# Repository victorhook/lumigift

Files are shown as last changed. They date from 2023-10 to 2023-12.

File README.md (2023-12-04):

# Lumigift

Lumigift is designed to be an awesome-looking illuminated christmas gift packet! The project consists of:
1. A PCB that contains:
   1. A microcontroller (STM32C0)
   2. 4 RGB LEDs (ws2812)
   3. A radio module (nrf24L01)
   4. Battery holder for a single AAA (1.5) battery
   5. Some other components to make it all work
2. Firmware for the microcontroller on the PCB, written with Arduino
3. A 3D printed box that the PCB fits into, designed in Fusion360
4. Software running on a PC to control the LED colors, written in Python. Note that this library uses a [Crazyradio PA](https://www.bitcraze.io/products/crazyradio-pa/) USB module and the [CrazyRadio](https://github.com/bitcraze/crazyflie-lib-python/blob/master/cflib/drivers/crazyradio.py) driver to control it from Python.
6. A simple webapp that can be used to configure the lumigifts.

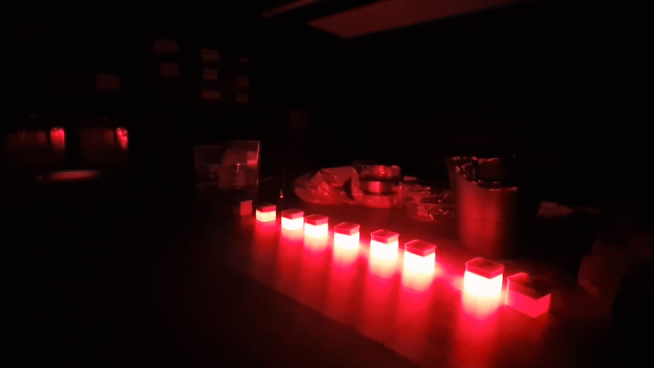
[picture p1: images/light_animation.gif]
Light animation


## Addressing
The PC controls the color of the LEDs through the Crazyradio PA which communicates with the NRF24L01 modules on the PCB. All lumigifts listens to the same address and dynamick payload is used, without any acks. This way, the PC acts as master and all lumigifts receives the same packages. This way, we can control the LEDs of all lumigifts easily. There is also support for controlling lumigifts individually, by assigning them unique IDs. This way, you can create cool light shows!

## Design

The PCB fits nicely in the 3D printed and the lid snaps on tight enough to keep it on.

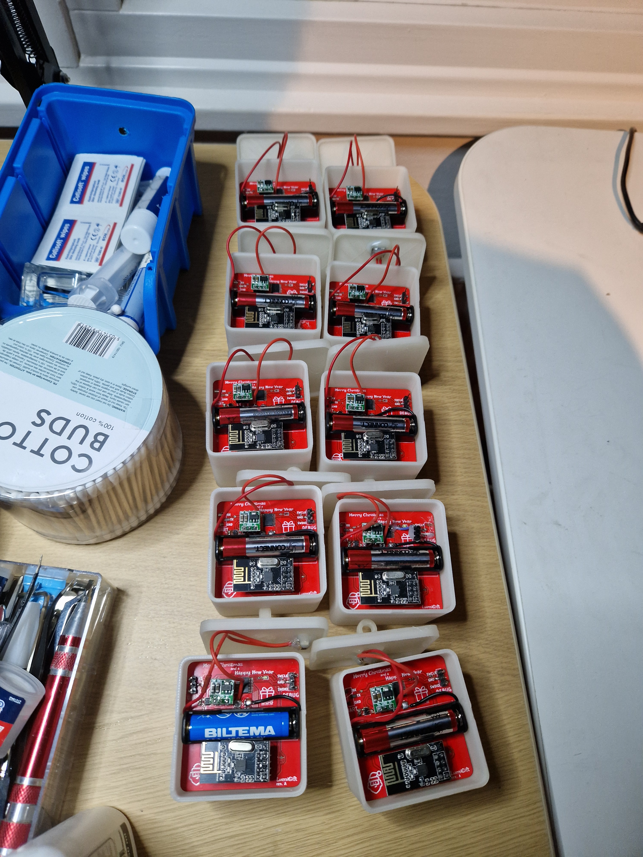
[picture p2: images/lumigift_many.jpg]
lumigift

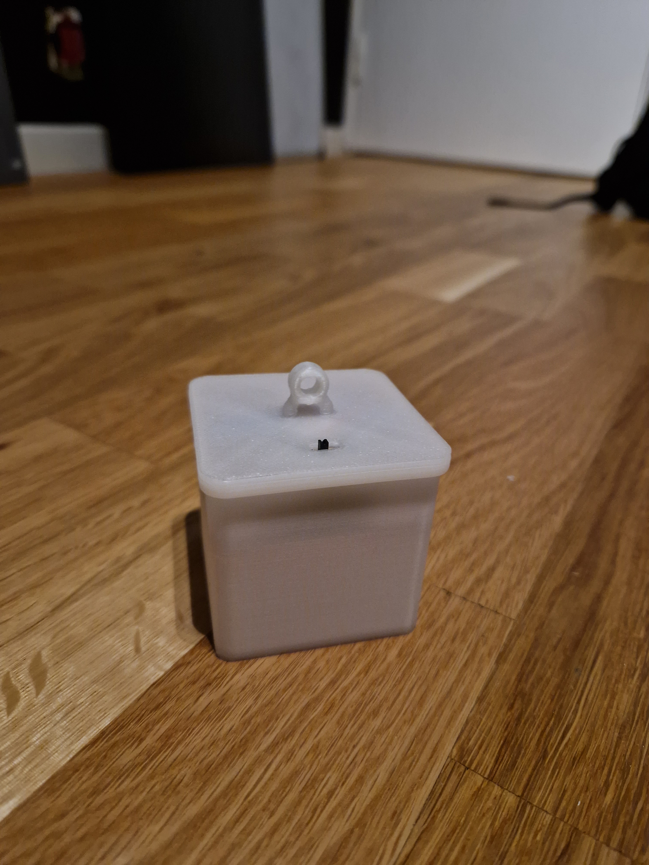
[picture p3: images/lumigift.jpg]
lumigift

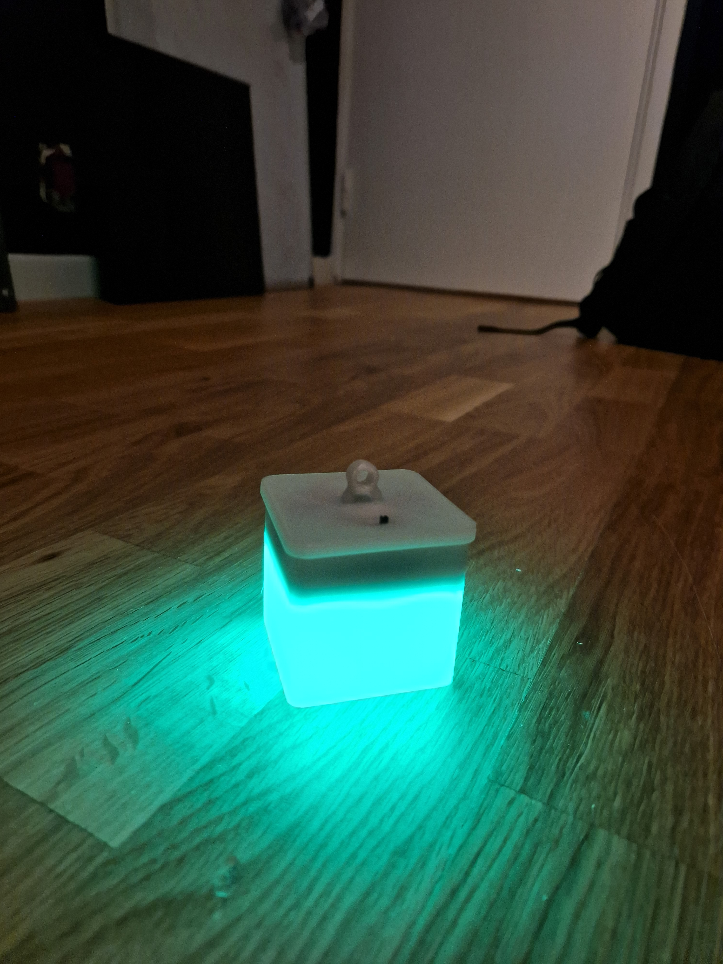
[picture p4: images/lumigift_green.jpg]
lumigift

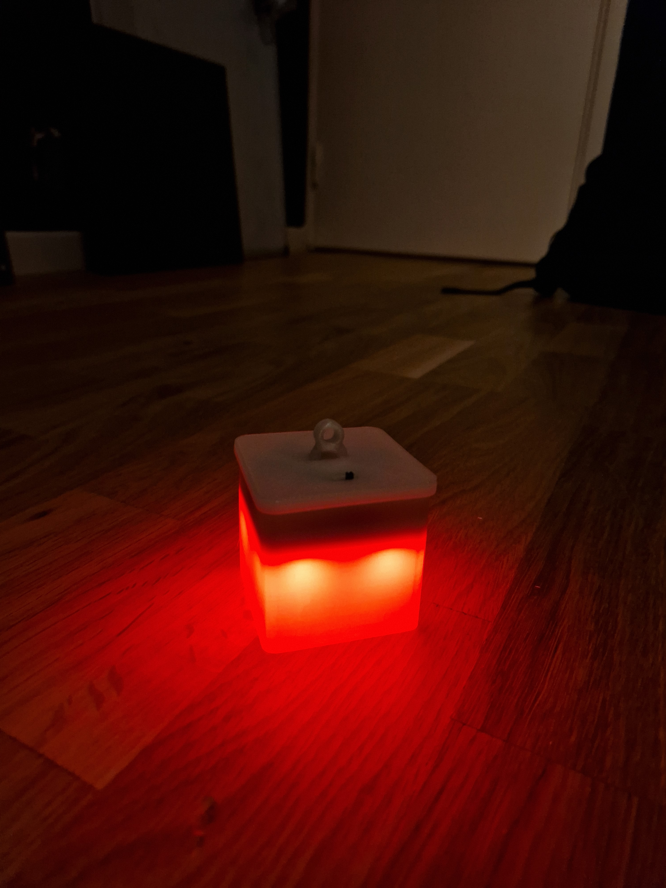
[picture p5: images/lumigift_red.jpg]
lumigift

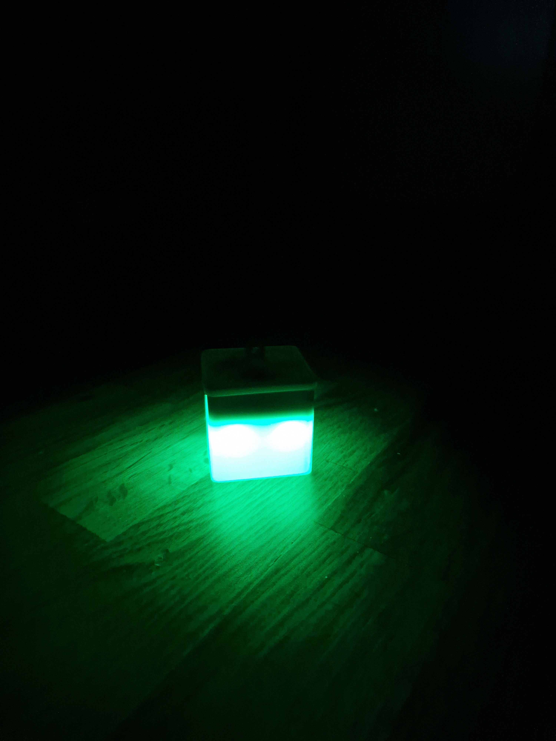
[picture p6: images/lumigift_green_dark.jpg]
lumigift


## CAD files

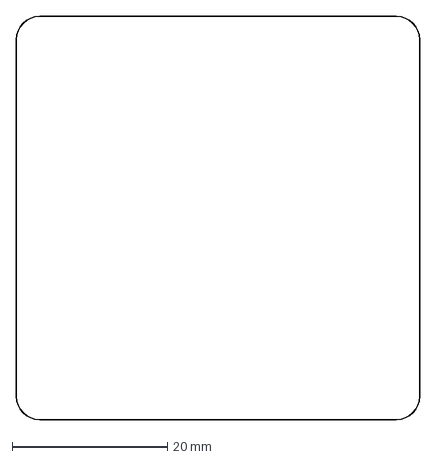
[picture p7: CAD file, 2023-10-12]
kicad/lumigift-rev-a/outline.dxf
52.0 x 52.0 mm

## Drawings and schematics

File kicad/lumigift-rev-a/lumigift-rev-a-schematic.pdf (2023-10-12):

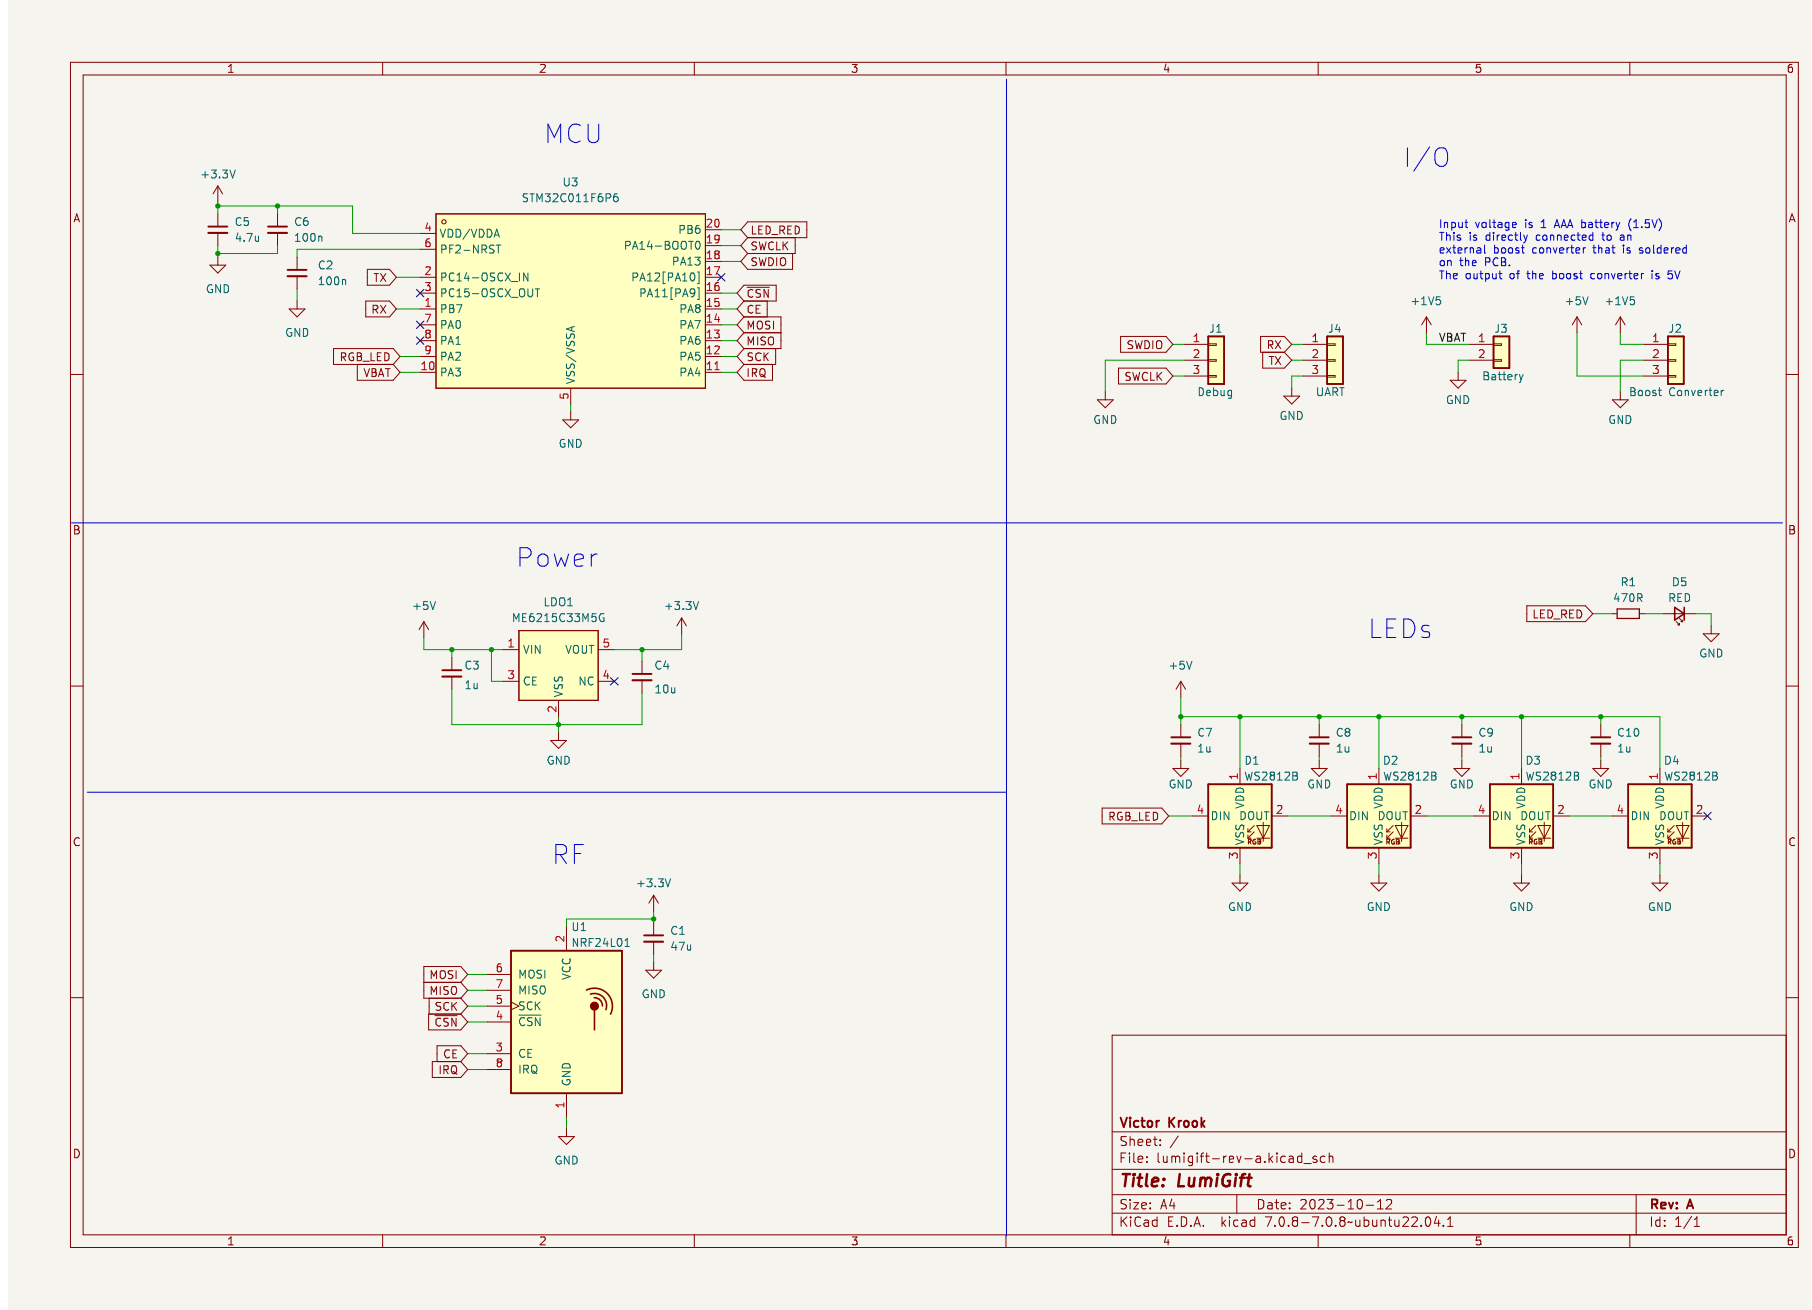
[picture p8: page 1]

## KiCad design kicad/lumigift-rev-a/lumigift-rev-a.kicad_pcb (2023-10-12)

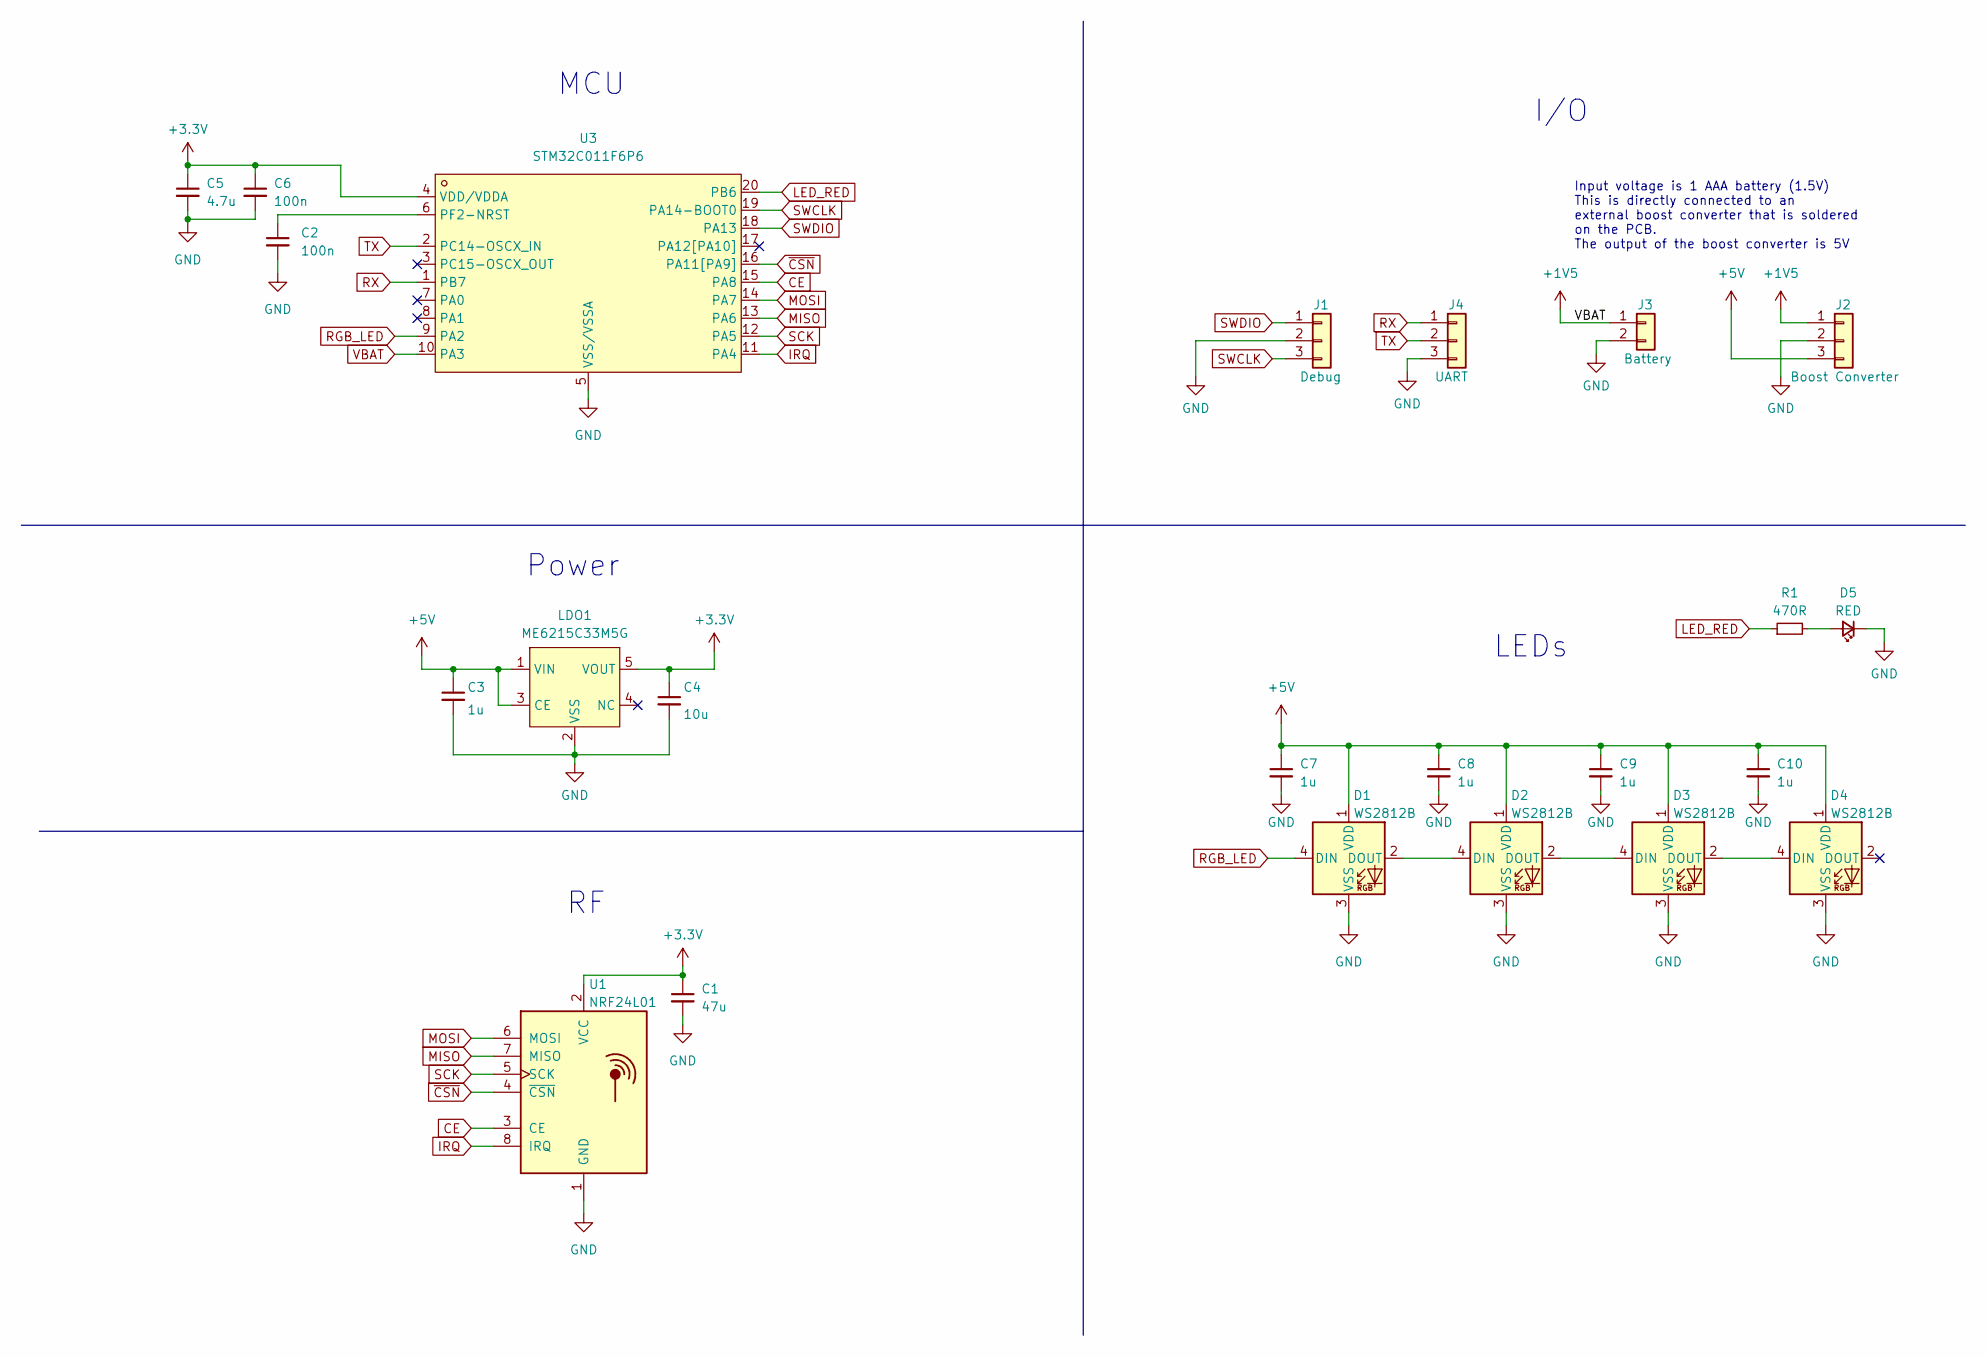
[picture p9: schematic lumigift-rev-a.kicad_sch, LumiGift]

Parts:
C1: 47u; C_1206_3216Metric
C2, C6: 100n; C_0402_1005Metric
C3, C7, C8, C9, C10: 1u; C_0402_1005Metric
C4: 10u; C_0805_2012Metric
C5: 4.7u; C_0805_2012Metric
D1, D2, D3, D4: WS2812B; LED_WS2812B_PLCC4_5.0x5.0mm_P3.2mm_No_Silk
D5: RED; LED_0603_1608Metric
J1: Debug; PinHeader_1x03_P2.54mm_Vertical_SMD_Pin1Left; MPN C5160786
J2: Boost Converter; PinHeader_1x03_P2.54mm_Vertical
J3: Battery; AAA_Battery_Holder
J4: UART; PinHeader_1x03_P2.54mm_Vertical_SMD_Pin1Left; MPN C5160786
LDO1: ME6215C33M5G; SOT-23-5_L3.0-W1.7-P0.95-LS2.8-BR; LCSC Part C84119
R1: 470R; R_0402_1005Metric
U1: NRF24L01; HDR-SMD_8P-P2.54-V-F-R2-C4-S7.1; MPN C3975149
U3: STM32C011F6P6; TSSOP-20_L6.5-W4.4-P0.65-LS6.4-BL; LCSC Part C5456198

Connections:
+3.3V: C1.1, C4.1, C5.1, C6.1, LDO1.5 (VOUT), U1.2 (VCC), U3.4 (VDD/VDDA)
+5V: C3.1, C7.1, C8.1, C9.1, C10.1, D1.1 (VDD), D2.1 (VDD), D3.1 (VDD), D4.1 (VDD), J2.3, LDO1.1 (VIN), LDO1.3 (CE)
CE: U1.3 (CE), U3.15 (PA8)
GND: C1.2, C2.2, C3.2, C4.2, C5.2, C6.2, C7.2, C8.2, C9.2, C10.2, D1.3 (VSS), D2.3 (VSS), D3.3 (VSS), D4.3 (VSS), D5.1 (K), J1.2, J2.2, J3.2, J4.3, LDO1.2 (VSS), U1.1 (GND), U3.5 (VSS/VSSA)
IRQ: U1.8 (IRQ), U3.11 (PA4)
LED_RED: R1.1, U3.20 (PB6)
MISO: U1.7 (MISO), U3.13 (PA6)
MOSI: U1.6 (MOSI), U3.14 (PA7)
unnamed: D1.2 (DOUT), D2.4 (DIN)
unnamed: D2.2 (DOUT), D3.4 (DIN)
unnamed: D3.2 (DOUT), D4.4 (DIN)
unnamed: D5.2 (A), R1.2
unnamed: C2.1, U3.6 (PF2-NRST)
RGB_LED: D1.4 (DIN), U3.9 (PA2)
RX: J4.1, U3.1 (PB7)
SCK: U1.5 (SCK), U3.12 (PA5)
SWCLK: J1.3, U3.19 (PA14-BOOT0)
SWDIO: J1.1, U3.18 (PA13)
TX: J4.2, U3.2 (PC14-OSCX_IN)
VBAT: J2.1, J3.1, U3.10 (PA3)
~CSN: U1.4 (~CSN), U3.16 (PA11[PA9])

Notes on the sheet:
Input voltage is 1 AAA battery (1.5V) This is directly connected to an external boost converter that is soldered on the PCB. The output of the boost converter is 5V
I/O
Power
MCU
LEDs

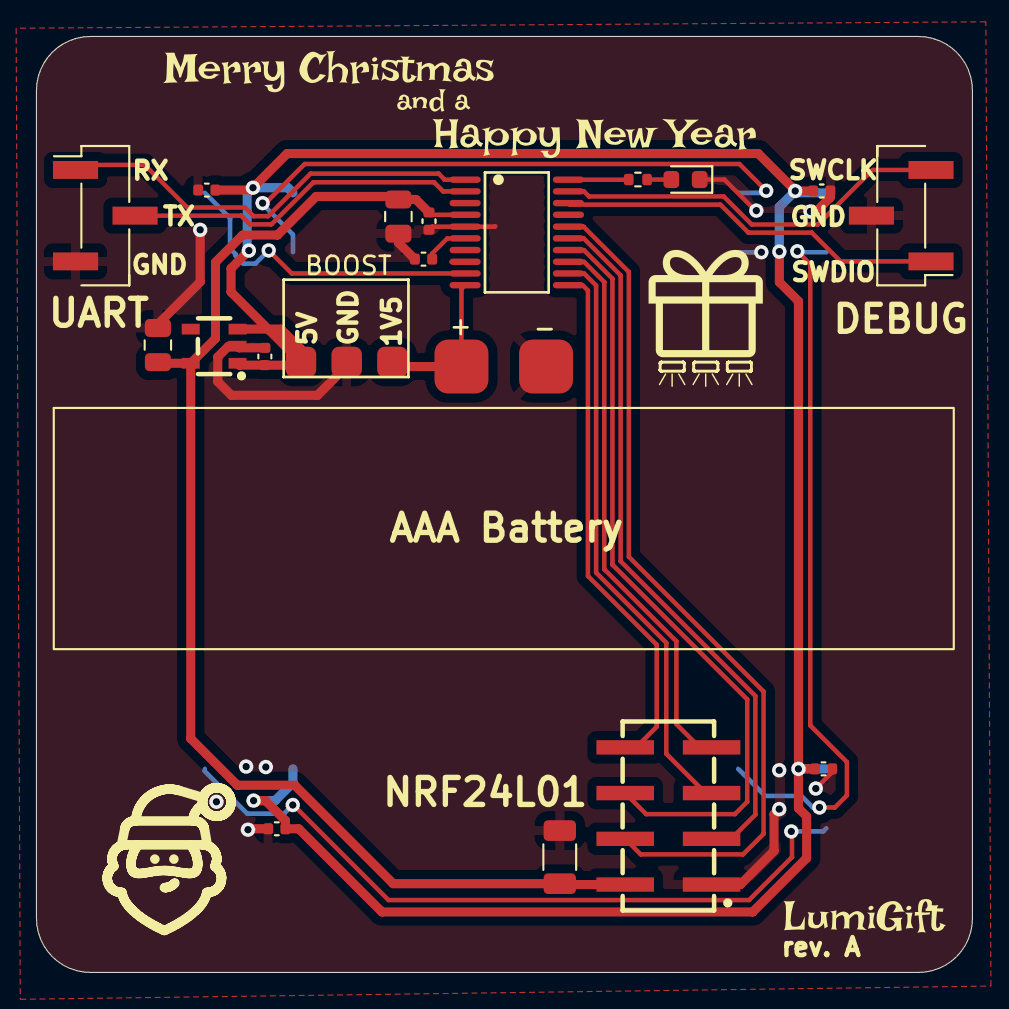
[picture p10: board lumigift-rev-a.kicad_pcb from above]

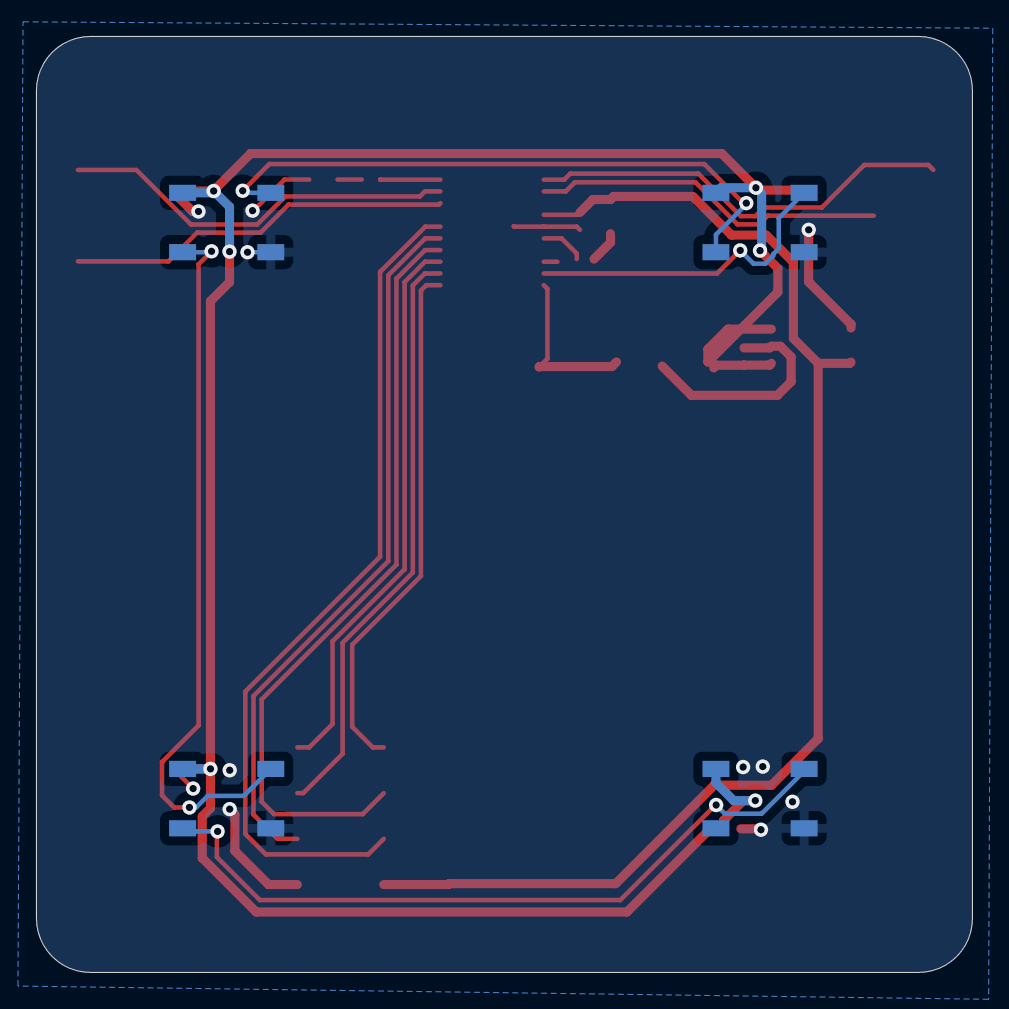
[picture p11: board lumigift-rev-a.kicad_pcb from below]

Board: 2 copper layers, 52.0 x 52.0 mm, 23 parts (4 on the bottom side), 21 nets.

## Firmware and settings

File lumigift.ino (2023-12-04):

#include <Arduino.h>
#include <SPI.h>
#include "RF24.h"
#include <Adafruit_NeoPixel.h>
#include <EEPROM.h>


#define PIN_UART_RX PB7
#define PIN_UART_TX PC14
#define PIN_RGB_LED PA2
#define PIN_LED PB6
#define PIN_VBAT PA3
#define PIN_CSN PA11
#define PIN_CE PA8
#define PIN_MOSI PA7
#define PIN_MISO PA6
#define PIN_SCK PA5
#define PIN_IRQ PA4

#define NUM_LEDS 4

// -- Structs & Enums -- //
typedef struct
{
    uint8_t r;
    uint8_t g;
    uint8_t b;
}__attribute__((packed)) color_t;

typedef struct
{
    color_t led_1;
    color_t led_2;
    color_t led_3;
    color_t led_4;
}__attribute__((packed)) color_packet_t;

typedef struct
{
    color_t colors[10];  // We can have a total of 10 unique IDs
}__attribute__((packed)) color_with_id_packet_t;

typedef struct
{
    uint8_t from_id;
    uint8_t to_id;
}__attribute__((packed)) set_id_packet_t;

typedef struct
{
    uint8_t id;
}__attribute__((packed)) blink_packet_t;

typedef struct
{
    uint8_t id;
}__attribute__((packed)) reboot_packet_t;

typedef enum
{
    LUMIGIFT_PACKET_TYPE_COLOR          = 0x01,
    LUMIGIFT_PACKET_TYPE_COLOR_WITH_ID  = 0x02,
    LUMIGIFT_PACKET_TYPE_SET_ID         = 0x03,
    LUMIGIFT_PACKET_TYPE_BLINK          = 0x04,
    LUMIGIFT_PACKET_TYPE_REBOOT         = 0x05,
} lumigift_packet_type_t;

typedef union
{
    union
    {
        color_packet_t color;
        set_id_packet_t id;
    };
} lumigift_packet_payload_t;

typedef struct
{
    lumigift_packet_type_t packet_type;
    lumigift_packet_payload_t payload;
} lumigift_packet_t;

// -- Radio configs -- //
#define RADIO_POWER_LEVEL  RF24_PA_LOW
#define RADIO_CHANNEL      80
#define RADIO_ADDRESS_SIZE 5
#define RADIO_PAYLOAD_SIZE sizeof(lumigift_packet_t)
#define RADIO_DATA_RATE    RF24_250KBPS
#define RADIO_RX_PIPE      1

// -- Other defines -- //
#define PACKET_TIMEOUT_MS 500
#define EEPROM_ADDRESS_ID 0
#define DEFAULT_ID 0
#define MAX_ID     9

// -- Function definitions -- //
static void go_to_error();
static void blink_bootup_sequence();

/**
 * Sets the color to all LEDs
 */
static void set_color(const color_t color);

/**
 * Sets the color for each LED
 */
static void set_color_for_each_led(const color_t led_1, const color_t led_2, const color_t led_3, const color_t led_4);

static void blink(const uint32_t color);

static bool valid_id(const uint8_t id);


// -- Variables -- //
static RF24 radio(PIN_CE, PIN_CSN);
static uint8_t rx_address[RADIO_ADDRESS_SIZE]  = {0x42, 0x42, 0x42, 0x42, 0x01};
static uint8_t tx_address[RADIO_ADDRESS_SIZE] = {0x42, 0x42, 0x42, 0x42, 0x01};
static color_packet_t color = {0, 0, 0};
Adafruit_NeoPixel pixels(NUM_LEDS, PIN_RGB_LED, NEO_GRB + NEO_KHZ800);

static uint8_t current_id = 0;
static uint32_t last_packet_received = 0;
static bool connected = false;

void setup()
{
    // Initialize GPIO
    pinMode(PIN_LED, OUTPUT);
    pinMode(PIN_CSN, OUTPUT);
    pinMode(PIN_CE, OUTPUT);
    digitalWrite(PIN_LED, LOW);

    pixels.begin();
    pixels.clear();
    pixels.show();

    blink_bootup_sequence();

    // Uart for debug
    Serial.setTx(PIN_UART_TX);
    Serial.setRx(PIN_UART_RX);
    Serial.begin(115200);
    Serial.println("Initializing lumigift...");

    // SPI for radio
    SPI.setMOSI(PIN_MOSI);
    SPI.setMISO(PIN_MISO);
    SPI.setSCLK(PIN_SCK);

    // Radio
    if (!radio.begin(&SPI))
    {
        Serial.println("Failed to initialize radio!");
        go_to_error();
    }

    // Configure radio
    radio.setPALevel(RADIO_POWER_LEVEL);
    radio.enableDynamicPayloads();
    //radio.setPayloadSize(RADIO_PAYLOAD_SIZE);
    radio.setAddressWidth(RADIO_ADDRESS_SIZE);
    radio.setChannel(RADIO_CHANNEL);
    radio.setDataRate(RADIO_DATA_RATE);
    radio.setAutoAck(true);
    radio.openWritingPipe(tx_address);      // Uses pipe 0
    radio.openReadingPipe(RADIO_RX_PIPE, rx_address);
    radio.startListening();

    // Read our ID from EEPROM
    current_id = EEPROM.read(EEPROM_ADDRESS_ID);
    if (!valid_id(current_id))
    {
      Serial.printf("Found invalid ID in EEPROM (%d), using deafult, %d\n", current_id, DEFAULT_ID);
      set_id(DEFAULT_ID);
    }

    Serial.printf("Boot complete, starting to run with ID %d\n", current_id);
}

void loop()
{
	//Serial.println("Trying to read ")
    uint8_t rx_pipe;
    uint8_t rx_buf[RADIO_PAYLOAD_SIZE];
    lumigift_packet_payload_t* rx;
    color_packet_t* color;

    color_with_id_packet_t* color_with_id_packet;
    set_id_packet_t* set_id_packet;
    blink_packet_t* blink_packet;
    reboot_packet_t* reboot_packet;

    if (radio.available(&rx_pipe))
    {
        connected = true;
        uint8_t size = radio.getPayloadSize();
        radio.read(rx_buf, size);

        lumigift_packet_type_t packet_type = (lumigift_packet_type_t) rx_buf[0];
        uint8_t* packet_payload = &rx_buf[1];
        last_packet_received = millis();
        Serial.printf("[My ID: %d] New packet: %d, %d bytes\n", current_id, packet_type, size);

        switch (packet_type)
        {
            case LUMIGIFT_PACKET_TYPE_COLOR:
                color = (color_packet_t*) packet_payload;
                set_color_for_each_led(color->led_1, color->led_2, color->led_3, color->led_4);
                for (int i = 0; i < size; i++)
                {
                    Serial.printf("%02x ", ((uint8_t*) &rx_buf)[i]);
                }

                //Serial.printf("Color packet received: #%02x%02x%02x\n", rx.payload.color.r, rx.payload.color.g, rx.payload.color.b);
                //Serial.printf("1: #%02x%02x%02x, 2: #%02x%02x%02x, 3, #%02x%02x%02x, 4: #%02x%02x%02x", )
                break;
            case LUMIGIFT_PACKET_TYPE_COLOR_WITH_ID:
                color_with_id_packet = (color_with_id_packet_t*) packet_payload;
                Serial.printf(
                  "%02x%02x%02x\n", 
                  color_with_id_packet->colors[current_id].r,
                  color_with_id_packet->colors[current_id].g,
                  color_with_id_packet->colors[current_id].b
                );
                set_color(color_with_id_packet->colors[current_id]);
                break;
            case LUMIGIFT_PACKET_TYPE_SET_ID:
                set_id_packet = (set_id_packet_t*) packet_payload;
                //Serial.printf("CONFIG: %d -> \n", set_id_packet->from_id, set_id_packet->to_id);
                if (set_id_packet->from_id == current_id)
                {
                  if (valid_id(set_id_packet->to_id))
                  {
                    Serial.printf("Switching ID from %d to %d!\n", set_id_packet->from_id, set_id_packet->to_id);
                    set_id(set_id_packet->to_id);
                    blink(0x00FF00);
                  }
                }
                break;
            case LUMIGIFT_PACKET_TYPE_BLINK:
                blink_packet = (blink_packet_t*) packet_payload;
                //Serial.printf("BLINK: %d\n", blink_packet->id);
                if (blink_packet->id == current_id)
                {
                  blink(0x00FFFF);
                }
                break;
            case LUMIGIFT_PACKET_TYPE_REBOOT:
                reboot_packet = (reboot_packet_t*) packet_payload;
                if (reboot_packet->id == current_id)
                {
                  // Let's reboot the system
                  blink(0xFF0000);
                  NVIC_SystemReset();
                }
                //Serial.printf("REBOOT: %d\n", reboot_packet->id);
                break;
        }

    }

    // Check if it's been too long since packet received, if so, we'll turn off LEDs to save power
    if (connected && (millis() - last_packet_received) > PACKET_TIMEOUT_MS)
    {
        Serial.println("Disconnected!");
        pixels.clear();
        pixels.show();
        connected = false;
    }
}

static void set_color(const color_t color)
{
    pixels.clear();
    pixels.setPixelColor(0, color.r, color.g, color.b);
    pixels.setPixelColor(1, color.r, color.g, color.b);
    pixels.setPixelColor(2, color.r, color.g, color.b);
    pixels.setPixelColor(3, color.r, color.g, color.b);   
    pixels.show();
}

static void set_color_for_each_led(const color_t led_1, const color_t led_2, const color_t led_3, const color_t led_4)
{
    pixels.clear();
    pixels.setPixelColor(0, led_1.r, led_1.g, led_1.b);
    pixels.setPixelColor(1, led_2.r, led_2.g, led_2.b);
    pixels.setPixelColor(2, led_3.r, led_3.g, led_3.b);
    pixels.setPixelColor(3, led_4.r, led_4.g, led_4.b);   
    pixels.show();
}


static void go_to_error()
{
    while (1)
    {
        digitalWrite(PIN_LED, HIGH);
        delay(1000);
        digitalWrite(PIN_LED, LOW);
        delay(1000);
    }
}


static void blink_bootup_sequence()
{
  blink(0x0000FF);
}

static void blink(const uint32_t color)
{
  for (int i = 0; i < 3; i++)
    {
        pixels.fill(color, 0, NUM_LEDS);
        pixels.show();
        delay(100);
        pixels.clear();
        pixels.show();
        delay(100);
    }
}

static bool valid_id(const uint8_t current_id)
{
  return (current_id >= 0) && (current_id <= MAX_ID);
}

static void set_id(const uint8_t new_id)
{
  EEPROM.write(EEPROM_ADDRESS_ID, new_id);
  current_id = new_id;
}

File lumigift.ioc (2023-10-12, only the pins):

Mcu.UserName=STM32C011F6Px
PA13.Signal=DEBUG_SWDIO
PA14-BOOT0.Signal=DEBUG_SWCLK
PA2.Signal=S_TIM1_CH3
PA3.Signal=ADC1_IN3
PA4.Signal=GPIO_Output
PA5.Signal=SPI1_SCK
PA6.Signal=SPI1_MISO
PA7.Signal=SPI1_MOSI
PA8.Signal=GPIO_Output
PB6.Signal=GPIO_Output
PB7.Signal=USART1_RX

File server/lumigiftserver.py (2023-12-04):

from ctypes import ArgumentError
from dataclasses import dataclass
from enum import IntEnum
from queue import Empty, Queue
import struct
from threading import Event, Thread
from time import sleep
import time
from typing import List
from crazyradio import Crazyradio


ADDRESS = (0x42, 0x42, 0x42, 0x42, 0x01)
CHANNEL = 80
DATARATE = Crazyradio.DR_250KPS
POWER = Crazyradio.P_0DBM
BROADCAST_FREQUENCY_HZ = 100

NBR_OF_LUMIGIFTS = 10


def as_hex_string(raw: bytes) -> str:
    return ' '.join(hex(a)[2:].zfill(2) for a in raw)

def get_radio() -> Crazyradio:
    try:
        radio = Crazyradio()
        radio.set_address(ADDRESS)
        radio.set_channel(CHANNEL)
        radio.set_data_rate(DATARATE)
        radio.set_power(POWER)
        radio.set_ack_enable(True)
        radio.set_cont_carrier(False)
    except Exception as e:
        print(e)
        radio = None

    return radio

class LumigiftPacketType(IntEnum):
    COLOR          = 0x01
    COLOR_WITH_ID  = 0x02
    SET_ID         = 0x03
    BLINK          = 0x04
    REBOOT         = 0x05

@dataclass
class LumigfitPacket:
    cmd: LumigiftPacketType
    raw: bytes

class PacketConstructor:

    def _hex_color_to_three_bytes(hex_color: str) -> bytes:
        return struct.pack(
            'BBB',
            int(hex_color[0:2], 16), # R
            int(hex_color[2:4], 16), # G
            int(hex_color[4:6], 16)  # B
        )

    @classmethod
    def make_color_individual_address_packet(cls, colors: List[str]) -> LumigfitPacket:
        pkt = struct.pack('B', LumigiftPacketType.COLOR_WITH_ID)
        for color in colors:
            pkt += cls._hex_color_to_three_bytes(color)

        return LumigfitPacket(cmd=LumigiftPacketType.COLOR_WITH_ID, raw=pkt)

    @classmethod
    def make_set_id_packet(cls, from_id: int, to_id: int) -> bytes:
        return LumigfitPacket(
            cmd=LumigiftPacketType.COLOR_WITH_ID,
            raw=struct.pack('BBB', LumigiftPacketType.SET_ID, from_id, to_id)
        )

    @classmethod
    def make_blink_packet(cls, id: int) -> bytes:
        return LumigfitPacket(
            cmd=LumigiftPacketType.BLINK,
            raw=struct.pack('BB', LumigiftPacketType.BLINK, id)
        )

    @classmethod
    def make_reboot_packet(cls, id: int) -> bytes:
        return LumigfitPacket(
            cmd=LumigiftPacketType.REBOOT,
            raw=struct.pack('BB', LumigiftPacketType.REBOOT, id)
        )


class LumigiftServer:

    packets_sent = 0

    def __init__(self, color_broadcast_frequency: int = BROADCAST_FREQUENCY_HZ) -> None:
        self._tx = Queue() # Queue[LumigfitPacket]
        self._stop_flag = Event()
        self._radio: Crazyradio = None
        self._colors: List[str] = ['000000' for i in range(NBR_OF_LUMIGIFTS)]
        self._color_broadcast_frequency = color_broadcast_frequency

        print('Initializing radio')
        self._radio = get_radio()
        print('Radio initialized')

        if self._radio is None:
            raise RuntimeError('Failed to connect to Crazy radio!')

        print(f'Using Crazyradio with address {ADDRESS}, channel {CHANNEL}, data rate: {DATARATE}, power: {POWER}')
        Thread(target=self._tx_thread, daemon=True).start()

    def start(self) -> None:
        self._stop_flag.clear()
        Thread(target=self._broadcast_thread, daemon=True).start()

    def stop(self) -> None:
        self._stop_flag.set()

    def set_colors(self, colors: List[str]) -> None:
        '''
        Sets the colors of the lumigifts with IDs: 0-NBR_OF_LUMIGIFTS.
        `colors` should be a list of NBR_OF_LUMIGIFTS hex color strings, for each lumigift
        '''
        if len(colors) != NBR_OF_LUMIGIFTS:
            raise ArgumentError(f'Expecting `colors` to be of size {NBR_OF_LUMIGIFTS}')
        self._colors = colors

    def blink_sequence(self, delay_ms: int = 1000) -> None:
        def _run():
            for i in range(NBR_OF_LUMIGIFTS):
                self.blink(i)
                time.sleep(delay_ms / 1000)

        Thread(target=_run, daemon=True).start()

    def set_id(self, from_id: int, to_id: int) -> None:
        self._tx.put(PacketConstructor.make_set_id_packet(from_id, to_id))

    def blink(self, id: int) -> None:
        self._tx.put(PacketConstructor.make_blink_packet(id))

    def reboot(self, id: int) -> None:
        self._tx.put(PacketConstructor.make_reboot_packet(id))

    def _broadcast_thread(self) -> None:
        print('Broadcasting started')

        period_s = 1.0 / self._color_broadcast_frequency

        while not self._stop_flag.is_set():
            next_broadcast = time.time() + period_s

            # Put broadcast packet in TX queue
            #print(self._colors)
            self._tx.put(PacketConstructor.make_color_individual_address_packet(self._colors))

            time_to_sleep = next_broadcast - time.time()
            if time_to_sleep > 0:
                sleep(time_to_sleep)

        print('Broadcasting stopped')

    def _tx_thread(self) -> None:
        while True:
            try:
                tx: LumigfitPacket = self._tx.get(block=True, timeout=1)
                #print(f'[{self.packets_sent}] TX: {tx.cmd.name}: {as_hex_string(tx.raw)} (len={len(tx.raw)})')
                self.packets_sent += 1
                res = self._radio.send_packet(tx.raw)
                #print(f'[TX {self.packets_sent}: {self._broadcast_color}] {len(tx)} bytes, res: {res.data}')
            except Empty:
                pass


if __name__ == '__main__':
    server = LumigiftServer()
    server.start()

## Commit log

2023-10-12 PCB Rev. A done
    [lumigift-rev-a.kicad_pcb, lumigift-rev-a.kicad_sch, outline.dxf]
2026-11-01 Rewrite Lumigift in Rust: radio bootloader, nRF24 USB bridge, host core, audio, 3D studio
    Replaces the Arduino firmware, the Crazyradio dependency and the Flask server with a
    from-scratch Rust stack:
    - crates/: shared no_std crates (nrf24 driver, nrf24-usb-proto, lumigift-proto, lumigift-fx)
    - firmware/lumigift: write-protected 10 KiB radio bootloader + app for the STM32C011
    (fast multicast OTA with bitmap repair, never-brick recovery, channel fallback)
    - firmware/nrf24-usb-bridge: generic STM32F103 nRF24 <-> native USB vendor bridge
    - host/: nusb bridge driver, link core with simulator, audio analysis + show engine,
    wgpu 3D stage, egui studio app, and CLI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
2026-11-02 Calmer music sync, 12 new LED looks and a Lighting page
    Music sync
    - Rhythm confidence per track and section; free-tempo music (solo violin,
    rubato, ambient) turns beat sync off instead of inventing a tempo
    - New onset detector with adaptive threshold; engine smoothing
    - Per-show Reactivity settings (beat sync, sensitivity, smoothing, intensity)
    - Fix the preview running ~26 ms ahead of the audio (radio latency was
    applied to the local preview too)
    - Link sends each beat/onset/drop flag exactly once, however fast the UI
    updates the show frame (no more double-triggered sparkles)
    - Eagerness metrics + example to measure it
    Lighting
    - lumigift-fx: Fade, Waterfall, Knight Rider, Blink, Tw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
2026-11-03 Bring-up on real hardware: USB bootloader for the dongle, link and ADC fixes
    Tested with the real dongle (STM32F103 + nRF24L01+PA/LNA) and a Lumigift.
    Dongle
    - USB DFU bootloader (boot/, 11 KiB of 16 KiB): never writes itself, commits
    the app's vector-table page last, enters on request, missing app or a
    double reset press; DfuSe, works with dfu-util
    - App moved to 0x08004000 with a DFU runtime interface (DETACH -> bootloader)
    - `lumigift bridge-update <elf|bin>` (nrf24_usb::dfu): detach, erase, write,
    read back, restart; DfuSe client tested against a bootloader model
    - Never enter USB suspend: a spurious WKUP right after SUSP left embassy's
    stack suspended, so every open after a hos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
2026-11-03 Clean up bring-up code: one access-retry helper, simpler reply state, tidier bootloader timer
    - nrf24-usb dfu: with_access() for the udev permission race (open, reopen
    after restart), simpler DfuSe layout parsing, fewer debug logs
    - Gift app: the pending command reply replaces reply_is_status; the
    100 ms status refresh always runs and drops a stale reply
    - Bridge bootloader: wrap-safe u32 reboot delay
    - Stage: iterator loops (clippy)
2026-11-03 Stabilise the radio link and firmware updates (measured on hardware)
    - Gifts wait until the nRF has sent a packet's ack before reloading the
    ack payload (app and bootloader). Flushing the TX FIFO mid-ack cut it
    short: ~60 % of unicasts needed a retransmission; now ~0 %.
    - OTA erases first, then streams: the host pauses for the image's page
    erases (the bootloaders erase ahead when idle) and streams at the
    programming rate. Streaming during erases lost ~3-10 % per pass.
    - Flash timing calibrated to the real STM32C011 (~140 us effective per
    double word): 2,000 chunks/s; the simulator uses the same model.
    - One gift, 18.6 KB: 0.70 s, ~1.5 % first-pass loss, 10/10 updates good.
    Co-Auth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
2026-11-03 Low-power doze for the gifts, deeper bridge queue, OTA hardening
    Gift (measured on hardware, 1.5 V supply, LEDs off: 106 mA -> 12 mA dozing)
    - Awake: the main loop sleeps (WFI) between a 1 kHz tick and radio IRQs
    - Doze: LEDs dark, ADC off, system clock on the 32 kHz LSI with HSI48 off,
    nRF in standby-I with a 2 ms receive window every second; only a Wake
    broadcast or a unicast wakes it. Entered on Broadcast::Sleep or after
    60 s without host traffic.
    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
2026-11-03 Health: frame reception from the gifts' own counters, settle time after waking
    - bcast_rx_pct = received / (received + sequence gaps), as counted by the
    gift. Comparing with frames sent relied on matching each status to the
    moment it describes, which the gifts' 100 ms status refresh skews: single
    windows read low and kept "Missing frames" lit while RX showed 100 %.
    - GiftView::online_since. The Studio waits 10 s after a gift comes online
    or reboots before warning about clock sync or frames (a woken gift needs
    ~2.5 s to re-acquire the bridge clock at the idle beacon rate).
    - examples/show_watch: per-gift reception and sync during a show.
    Measured on 3 gifts: 99.7-100 % reception, 0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
2026-11-04 Music colours from pitch, one colour per gift (work from the parallel session)
    - lumigift-audio: harmonic pitch-class detection (dsp::ToneDetector, shared
    by the offline analysis and the live analyzer): per-frame tone (note or
    chord root on the pitch circle) and clarity; ShowSettings::note_color so
    melodies and chord changes drive the colour
    - lumigift-fx: a gift lights its four LEDs in one colour (they blend inside
    the frosted box anyway); spatial looks move across the gifts instead
    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
2026-11-04 Wake bursts timed by the bridge; honest TX failure stats; slower idle sweep
    Wake (measured on 10 gifts, PC at load ~16):
    - New bridge command TxRepeat: one NO_ACK payload back to back for N ms
    (keeping to the nRF's 4 ms TX-mode budget per run), then one TxDone.
    Wake bursts use it, so they have no gaps whatever the host does; the
    scheduler sends nothing else meanwhile and pauses pings.
    - Before: the burst was fed in 32-packet jobs from the host; stalls on a
    busy PC left gaps that swallowed gifts' 2 ms listen windows, and only
    6-10 of 10 gifts woke. Now 8/8 cycles woke all 10.
    - Falls back to the host-fed burst with older bridge firmware; the
    simulator models TxRepeat.
    Stats and d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
2026-11-04 Studio: recovery-mode hint says to reboot first
    The bootloader stays in recovery after three app resets in a row (e.g. a
    flat battery browning out under LED load); a reboot brings the app back,
    as it did for a gift on a 0.8 V cell. "Update the firmware" was the
    wrong first step.
2026-11-05 Gift clock sync locks on the 10 Hz idle beacons ("Clock drift" fix)
    6 of 10 gifts never reported synced while the host was idle. The anchor
    window was 8 samples: 80 ms at 100 Hz show frames, but 800 ms at the 10 Hz
    idle beacons, i.e. 8+ ms of drift on a gift whose HSI48 is ~1 % off (no
    crystal), beyond STEP_US, so it re-seeded forever.
    - A window also closes after 80 ms (WINDOW_SPAN_US), checked before the
    new sample is judged
    - Once locked, a sample >1 ms later than the model is a delayed read and
    is skipped (with one sample per window nothing else would outvote it);
    4 in a row still re-seed
    - New test: 10 Hz samples, 0 to +-2 % clock error, read jitter and stalls:
    synced >99 % of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
2026-11-05 Stage: Set order, blink in sequence, shortcuts; Lighting Off; selection fixes
    - Stage "Set order": the gifts blink one at a time and you say where each
    stands in the room (click or 1-9/0); saving assigns slots 0..n in that
    order (Link::assign_slots_in_order, other holders move to free slots) and
    hands the stage's existing positions, left to right, to the gifts in room
    order
    - Blink all (or the selected) in sequence: Shift+B on Stage (left to right)
    and Fleet (slot order), header button, palette command
    - Stage shortcuts as on Fleet: B blink, S slot, Ctrl+A / Esc select all /
    clear; listed in the shortcut sheet
    - Clicking the floor clears the selection (Stage and Lighting): the st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
2026-11-05 Gifts cap LED power to what their battery can deliver
    The configured LED budget (250 mA at 5 V by default) needs ~1 A from the
    AAA cell at full brightness; a half-empty cell browns out and three resets
    in a row put the gift into recovery (seen on a 0.8 V cell).
    - battery_led_budget_ma: the current an AAA can sustain at the measured
    voltage (~700 mA fresh down to ~60 mA nearly flat) through the ~80 %
    efficient boost, as a 5 V budget (~150 mA fresh, ~70 mA at 1.15 V,
    <10 mA at 0.8 V); applies on top of the configured budget, so existing
    gifts get it without a config change. Nearly flat cells now dim instead
    of browning out.
    - The cap drops at once and recovers by 10 mA/s (the voltag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
2026-11-05 Studio: latency calibration by tapping along
    A metronome button next to the latency slider (real gifts only) opens a
    two-step tap-along:
    1. Listen: a 90 BPM click track on the selected output device, lights off;
    tap Space on each click. Offset = unreported audio delay + tap bias.
    2. Watch: no sound, white flashes on all gifts through the normal show
    output; tap on each flash. Offset = radio + render delay + tap bias.
    Latency = watch - listen (medians; the listener's tapping bias cancels),
    with the spread shown and a warning for irregular taps. The calibration
    plays on its own Player (the loaded song is paused, not replaced), owns
    the show output only while flashing, and the Studio pa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
2026-11-05 Battery measurement calibration (two points, bench supply)
    - Gift config: the two reserved bytes (zero on every gift) hold a gain and an
    offset: mv + mv * gain / 32768 + 2 * offset_2mv (layout::calibrate_vbat_mv);
    new config keys VBAT_GAIN / VBAT_OFFSET_MV. The gift corrects every reading,
    so the reported voltage, the low-battery flag and the battery LED cap all
    use the true value. Uncalibrated gifts are unchanged.
    - lumigift-core::calibration::vbat_calibration: gain and offset from two
    (raw, true) points, rejecting implausible input (points < 0.2 V apart,
    reading not following the supply, gain error > 20 %, offset > 254 mV)
    - CLI: hidden service command `calibrate-vbat <gift> [-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
2026-11-05 Bridge dongle case (OpenSCAD source + STLs)
    A two-part printable case for the bridge: STM32 board at the bottom, the
    nRF24L01+PA+LNA module above it, USB-C at one end and the SMA connector at
    the other; snap-fit lid. See mechanical/bridge-case/README.md.
2026-11-06 Gifts: fix the LED power limiter going black, smooth the battery cap
    power_limit divided by an extra 255 and scaled the LEDs to ~0 whenever it
    had to limit. It never triggered before (250 mA budget > 244 mA full white);
    the battery cap made it trigger, so gifts lit briefly and went dark. Its
    test now also checks the draw lands at the budget.
    The battery is now read 10 times a second and averaged over ~0.8 s
    (single readings swing ±150 mV with the boost converter's pulsed load),
    so the cap no longer makes the LEDs pump.
2026-11-06 Remove the configurable LED power budget
    At its default it never limited anything, and max brightness already
    dims. The battery cap alone limits LED power now; config key 3 is
    rejected and its config bytes are reserved.
